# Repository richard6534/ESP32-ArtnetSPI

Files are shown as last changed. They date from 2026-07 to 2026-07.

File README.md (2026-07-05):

# ESP32-ArtnetSPI
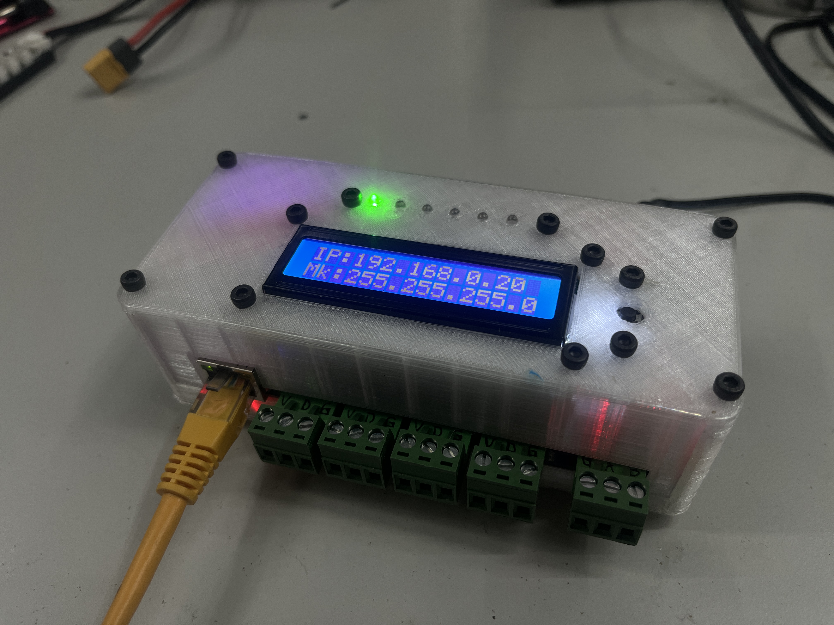
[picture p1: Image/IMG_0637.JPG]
Image Description


這款 Artnet SPI ESP32 LED 控制器是一款高效能的開源解決方案，可透過乙太網路或 Wi-Fi 控制可尋址 LED。此專案可讓您使用 Artnet 協議，透過配備 W5500 乙太網路模組及 ESP32 微控制器來控制多個 LED 燈條。程式碼包含一個簡單的 Web 伺服器，用於配置和控制 LED 燈條。為了獲得最佳效能。

## Features

- 4 個輸出端口，共 16 個燈路：每個輸出端口最多可連接 4 條 LED 燈帶，每個輸出端口有 4 個燈路，可實現大規模 LED 安裝。
- 1 個DMX輸出端口，可連接DMX相關設備。
- 支援 3 色（RGB）、4 色（RGBW）和 5 色（RGBAW）LED。
- 支援 3 線 LED (WS28xx) 和 4 線 SPI 時脈 LED (APA102)。
- 支援乙太網路和 Wi-Fi：支援有線和無線 Art-Net 控制，實現靈活的連線。
- 靜態 IP 位址選項適用於永久安裝。
- 用於在 artnet、靜態 IP、RGB 測試和靜態顏色之間切換模式的實體按鈕。
- 透過空中下載 (OTA) 更新，可以輕鬆地將您的節點更新到不同版本。
- 透過網頁介面配置 LED 數量、輸出埠、起始和節點名稱。
- 高幀率：超過 40 FPS，取決於所使用的軟體。
- 效能可靠：可靠性高達 99% 以上，丟幀率低於 1%。
- 支援 128x32 OLED 顯示器：提供即時狀態更新和設定回饋。
- 狀態 RGB LED：指示設備狀態，方便調試和監控。
- RGB 測試循環：利用內建循環模式快速測試 LED 輸出。
- 完全開源：包含 PCB 設計和 BOM，使用戶能夠建立自己經濟高效的控制器。

## Design Drawing

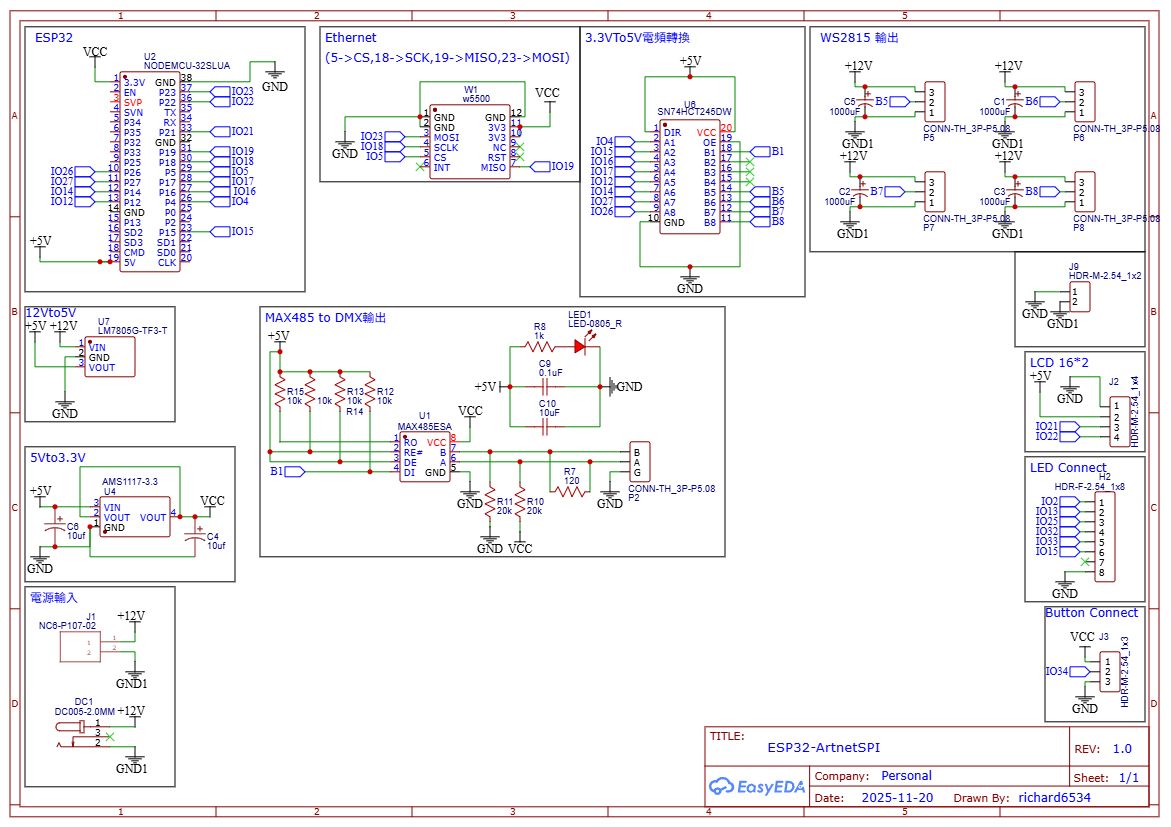
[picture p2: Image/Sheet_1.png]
Image Description

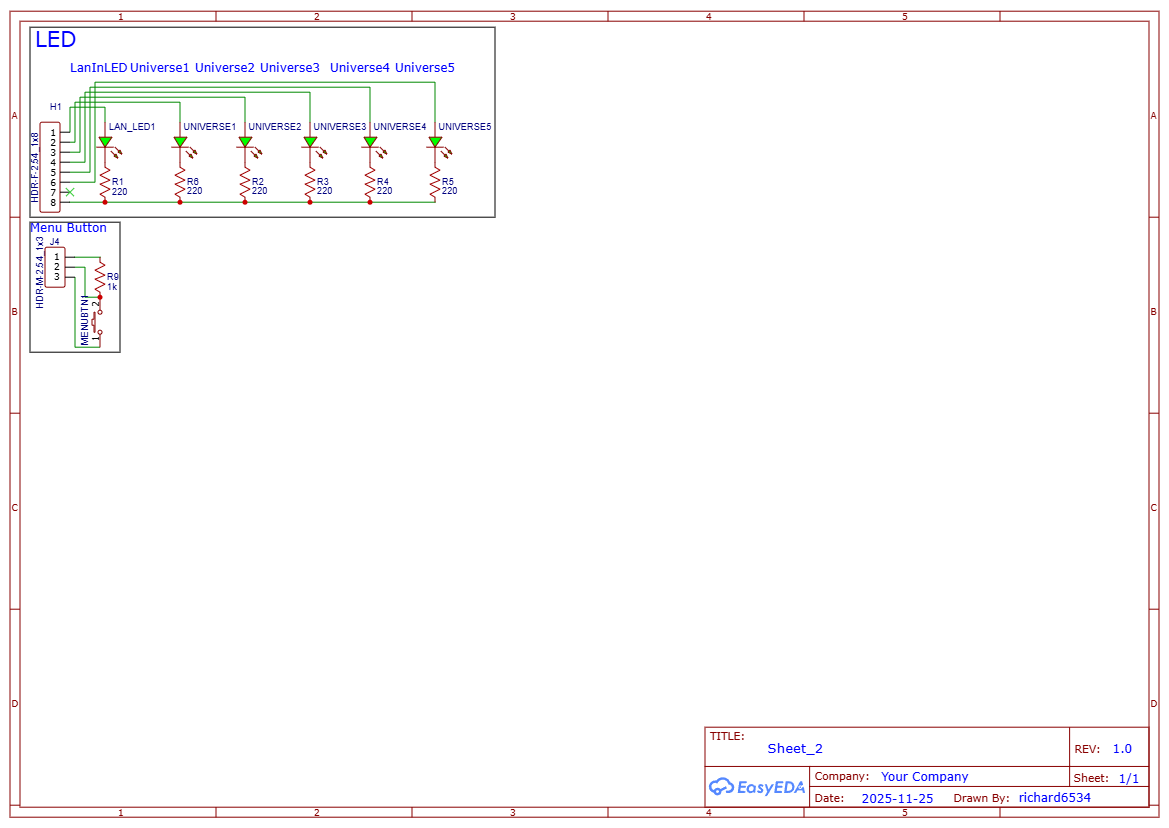
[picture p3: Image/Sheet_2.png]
Image Description


## PCB Design

- 這是正在進行中的PCB設計，採用12V轉5V降壓轉換器，並使用螺絲端子方便連接。

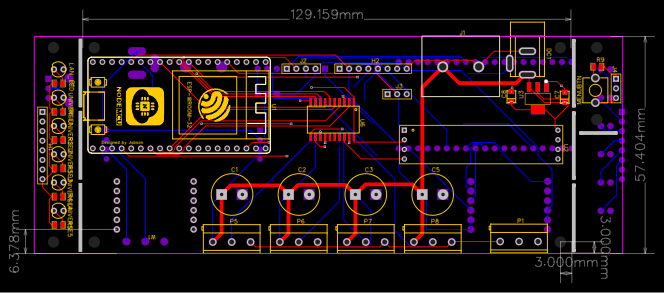
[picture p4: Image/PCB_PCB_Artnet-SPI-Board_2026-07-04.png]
Image Description


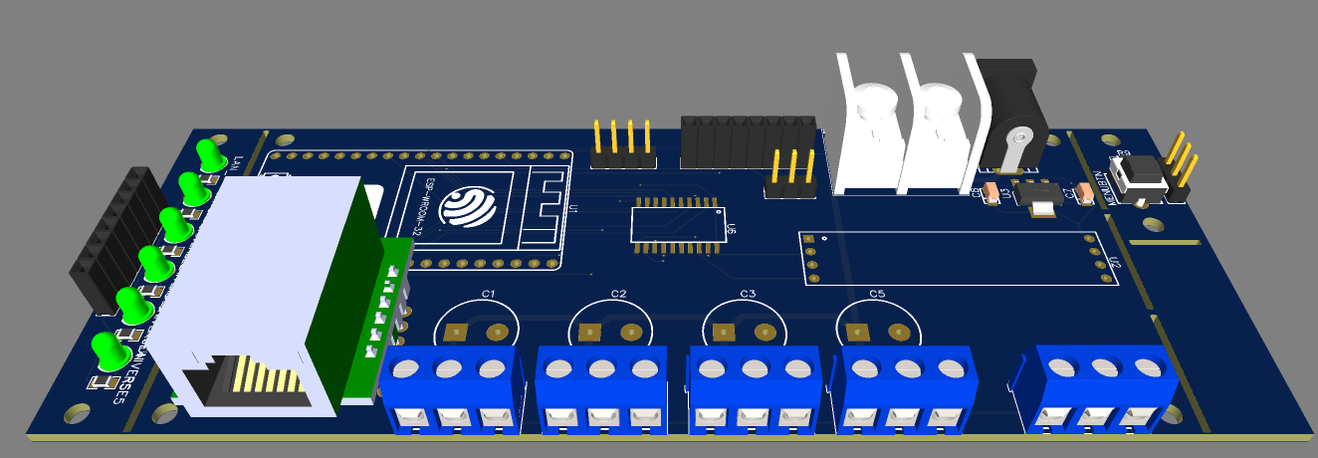
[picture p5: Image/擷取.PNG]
Image Description


## BOM

BOM_Artnet-SPI-Board.csv

## Hardware Requirements

- ESP32-S2-NodeMCU 
- W5500 Ethernet module
- WS2812 RGB 狀態指示燈（可選，用於狀態指示）)
- 12v/5v Power Supply

**Important!** 僅支援部分 ESP32 型號！使用 W5500 時，請查看 WebServer_ESP32_W5500 以了解支援的開發板。

## Software Requirements

- Arduino IDE with ESP32 support
- Espressif ESP32 board manager library
  - Use https://espressif.github.io/arduino-esp32/package_esp32_index.json
  - Version 2.0.17 or lower, otherwise compilation errors arise

## Supported LED ICs

All LEDs based on the wsXXXX and clocked LED series are supported. These can be 3, 4, or 5 channel LEDs. These include, but are not limited to:
  - WS2805, WS2811, WS2812, WS2813, WS2814, WS2815 (Tested)
  - APA102, SK6812 SPI-based LEDs (Tested)
  - SK6812, SK6812W, SK6812-mini (Not tested)
  - GS8208, TM1814, TM1829, UCS8904, UCS8903, FW1906 (Not tested)

# Configuration

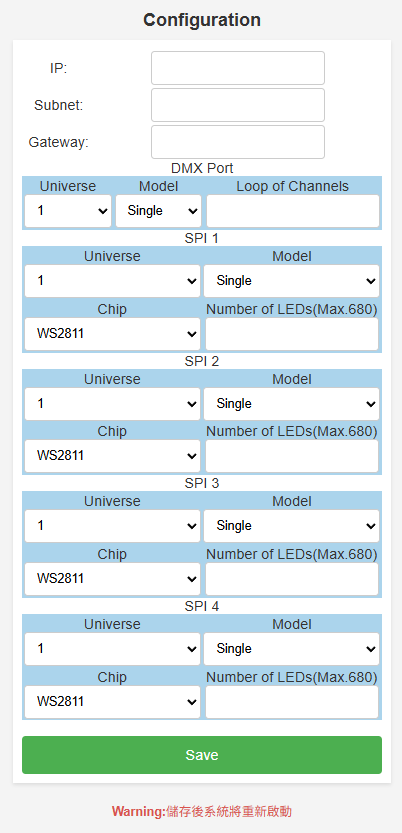
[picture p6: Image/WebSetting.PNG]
Image Description


## Access the Web Interface:
- 上傳程式碼後，使用 W5500 乙太網路模組將 ESP32 連接到網路。
- 找到指派給 ESP32 的 IP 位址，並在網頁瀏覽器中開啟它。
  - 若要輕鬆尋找 IP 位址，可以按上面的按鈕，即會顯示IP及目前設定。

# Test

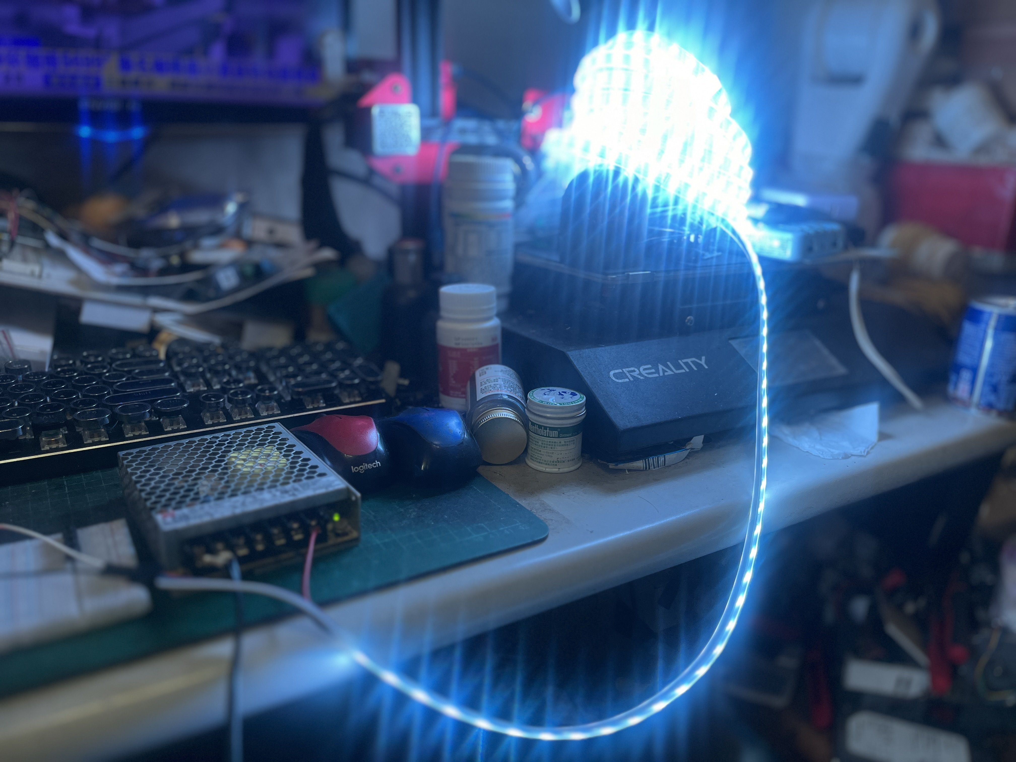
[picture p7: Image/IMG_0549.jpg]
Image Description


## Open-Source Contributions
This project is fully open-source! Feel free to contribute improvements, share your builds, and collaborate with the community.

##License
This project is released under the MIT License. You are free to use, modify, and distribute it with proper attribution.

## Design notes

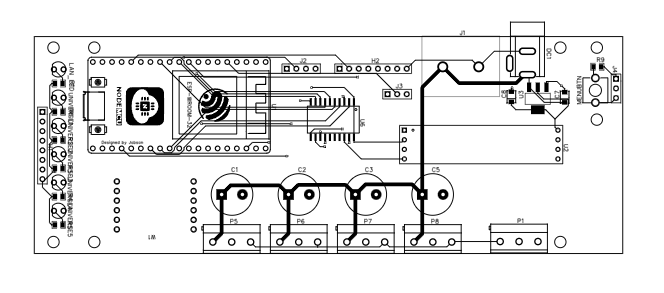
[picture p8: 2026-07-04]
Image/PCB_PCB_Artnet-SPI-Board_2026-04-16.png

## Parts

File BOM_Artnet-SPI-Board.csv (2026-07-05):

ID | Name | Designator | Footprint | Quantity | Manufacturer Part | Manufacturer | Supplier | Supplier Part
1 | 1000uF | C1,C2,C3,C5 | CAPACITOR1000UF16V | 4 | electrolytic capacitor10UF50V | ValuePro | LCSC | C32856
2 | DC005-2.0MM | DC1 | DC-IN-TH_DC005 | 1 | DC005-2.0MM | SOFNG | LCSC | C111567
3 | HDR-F-2.54_1x8 | H1,H2 | HDR-F-2.54_1X8 | 2 |  |  | LCSC | C225505
4 | NC6-P107-02 | J1 | NC6P10702 | 1 | NC6-P107-02 | TE Connectivity | Mouser | 571-14376644
5 | HDR-M-2.54_1x4 | J2 | HDR-M-2.54_1X4 | 1 |  |  | LCSC | C124378
6 | HDR-M-2.54_1x3 | J3,J4 | HDR-M-2.54_1X3 | 2 |  |  | LCSC | C180248
7 | LED-0805_G | LAN_LED1,UNIVERSE1,UNIVERSE2,UNIVERSE3,UNIVERSE4,UNIVERSE5 | LED0805_GREEN | 6 | NCD0805G1 | 国星光电 |  | C84260
8 | K2-3.6×6.1_SMD | MENUBTN1 | KEY-TH_L6.6-W6.3-P6.50-L | 1 | K2-1107ST-A4SW-06 |  | LCSC | C118141
9 | CONN-TH_3P-P5.08 | P1,P5,P6,P7,P8 | CONN-TH_3P-P5.08 | 5 |  |  | LCSC
10 | 220 | R1,R2,R3,R4,R5,R6 | R0805 | 6
11 | 1k | R9 | R0805 | 1
12 | NODEMCU-32SLUA | U1 | COMM-TH_NODEMCU-32SLUA | 1 | NodeMCU-32SLua | Ai-Thinker(安信可) | LCSC | C111436
13 | MAX485 | U2 | MAX485MODULE_FP | 1 | MAX485EESA+ | ADI(亚德诺)/MAXIM(美信) | LCSC | C7456067
14 | LM7805G-TF3-T | U3 | TO-220F-3_L10.2-W4.7-P2.54-L | 1 | LM7805G-TF3-T | UTC(友顺) | LCSC | C213490
15 | SN74HCT245DW | U6 | SOIC-20 | 1
16 | w5500 | W1 | W5500 | 1

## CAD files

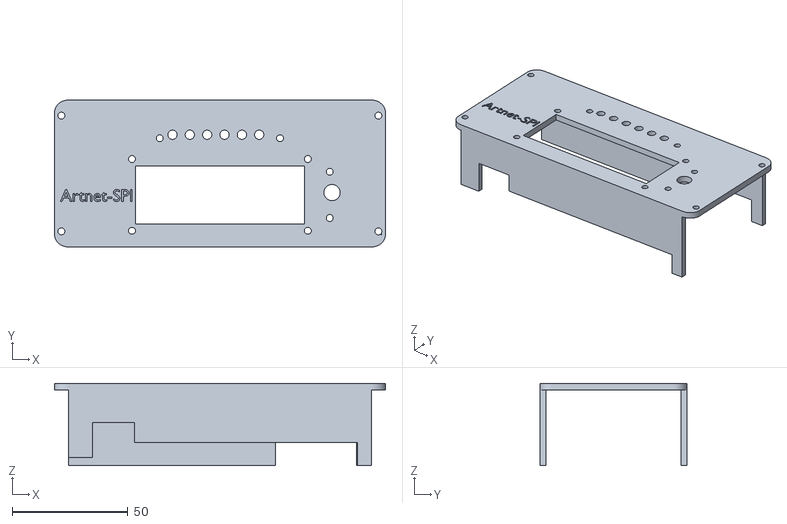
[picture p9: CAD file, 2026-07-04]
3DPrintFile/TopV2.stl
143.1 x 63.5 x 35.6

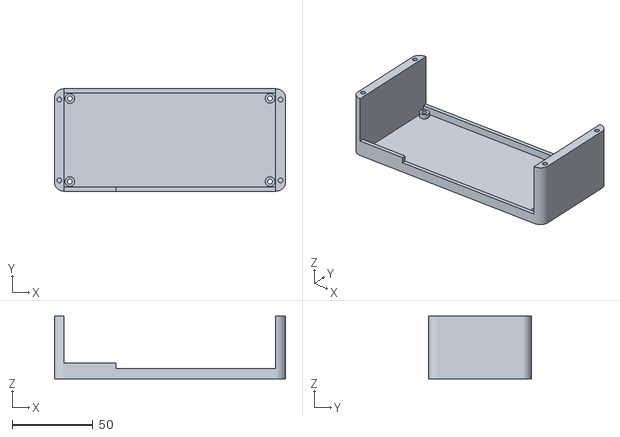
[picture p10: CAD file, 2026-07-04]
3DPrintFile/ButtomV2.stl
143.0 x 63.5 x 38.9

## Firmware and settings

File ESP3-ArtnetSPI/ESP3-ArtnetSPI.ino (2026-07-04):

#include <SPI.h>
#include <EEPROM.h>
#include <Ethernet.h>
#include <ArtnetEther.h>
#include <FastLED.h>
#include "HTML_UrlEncode.h"
#include "ESPDMX.h"
#include <Arduino.h>
#include <LiquidCrystal_I2C.h>
//---------------------------------------------------------------
// Set the static IP address to use if the DHCP fails to assign
// W5500 (5->CS,18->SCK,19->MISO,23->MOSI)
// replace the MAC address below by the MAC address printed on a sticker on the Arduino Shield 2
byte mac[] = { 0xDE, 0xAD, 0xBE, 0xEF, 0xFE, 0xEF };
EthernetClient client;
//---------------------------------------------------------------
ArtnetEtherReceiver artnet;
uint16_t universe1 = 0; 
uint16_t universe2 = 1;  
uint16_t universe3 = 2;  
uint16_t universe4 = 3;
uint16_t universe5 = 4;  
//---------------------------------------------------------------
// FastLED settings
const int numLeds = 512; // CHANGE FOR YOUR SETUP
const int numberOfChannels = numLeds * 3; // Total number of channels you want to receive (1 led = 3 channels)
//12, 14, 27, 26
const byte dataPin1 = 12;
const byte dataPin2 = 14;
const byte dataPin3 = 27;
const byte dataPin4 = 26;
CRGB leds1[numLeds];
CRGB leds2[numLeds];
CRGB leds3[numLeds];
CRGB leds4[numLeds];
//---------------------------------------------------------------
//LED Lan Universe1 Universe2 Universe3 Universe4->2,13,25,32,33,15
const byte Lan_LedPin = 2;
const byte UNI1_LedPin = 13;
const byte UNI2_LedPin = 25;
const byte UNI3_LedPin = 32;
const byte UNI4_LedPin = 33;
const byte UNI5_LedPin = 15;
//WebServer----------------------------------------------------------------
EthernetServer server(80);
String currentLine = "";                // make a String to hold incoming data from the client
String CMDString = "";
bool isCMD = false;
//DMX---------------------------------------------------------------
const byte DMXPin1 = 4;
DMXESPSerial dmx1;
//儲存程序----------------------------------------------------------
//EEPROM MAX 512
#define EEPROM_Status_SIZE 1
#define EEPROM_Status_Addr 0
byte IOT_Status = 0;
//StaticIP-----------------------------------------------------------
#define EEPROM_StaticIP_SIZE 20
#define EEPROM_StaticIP_Addr 1
//Subnet-------------------------------------------------------------------
#define EEPROM_Subnet_SIZE 20
#define EEPROM_Subnet_Addr 21
//Gateway-------------------------------------------------------------------
#define EEPROM_Gateway_SIZE 20
#define EEPROM_Gateway_Addr 41
//DMXPort_Universe-------------------------------------------------------------------
#define EEPROM_DMXPort_Universe_SIZE 1
#define EEPROM_DMXPort_Universe_Addr 61
//DMXPort_Model-------------------------------------------------------------------
#define EEPROM_DMXPort_Model_SIZE 1
#define EEPROM_DMXPort_Model_Addr 62
//DMXPort_Loop-------------------------------------------------------------------
#define EEPROM_DMXPort_Leds_SIZE 4
#define EEPROM_DMXPort_Leds_Addr 63
//SPI1_Universe-------------------------------------------------------------------
#define EEPROM_SPI1_Universe_SIZE 1
#define EEPROM_SPI1_Universe_Addr 67
//SPI1_Model-------------------------------------------------------------------
#define EEPROM_SPI1_Model_SIZE 1
#define EEPROM_SPI1_Model_Addr 68
//SPI1_Chip-------------------------------------------------------------------
#define EEPROM_SPI1_Chip_SIZE 1
#define EEPROM_SPI1_Chip_Addr 69
//SPI1_Leds-------------------------------------------------------------------
#define EEPROM_SPI1_Leds_SIZE 4
#define EEPROM_SPI1_Leds_Addr 70
//SPI2_Universe-------------------------------------------------------------------
#define EEPROM_SPI2_Universe_SIZE 1
#define EEPROM_SPI2_Universe_Addr 74
//SPI2_Model-------------------------------------------------------------------
#define EEPROM_SPI2_Model_SIZE 1
#define EEPROM_SPI2_Model_Addr 75
//SPI2_Chip-------------------------------------------------------------------
#define EEPROM_SPI2_Chip_SIZE 1
#define EEPROM_SPI2_Chip_Addr 76
//SPI2_Leds-------------------------------------------------------------------
#define EEPROM_SPI2_Leds_SIZE 4
#define EEPROM_SPI2_Leds_Addr 77
//SPI3_Universe-------------------------------------------------------------------
#define EEPROM_SPI3_Universe_SIZE 1
#define EEPROM_SPI3_Universe_Addr 81
//SPI3_Model-------------------------------------------------------------------
#define EEPROM_SPI3_Model_SIZE 1
#define EEPROM_SPI3_Model_Addr 82
//SPI3_Chip-------------------------------------------------------------------
#define EEPROM_SPI3_Chip_SIZE 1
#define EEPROM_SPI3_Chip_Addr 83
//SPI3_Leds-------------------------------------------------------------------
#define EEPROM_SPI3_Leds_SIZE 4
#define EEPROM_SPI3_Leds_Addr 84
//SPI4_Universe-------------------------------------------------------------------
#define EEPROM_SPI4_Universe_SIZE 1
#define EEPROM_SPI4_Universe_Addr 89
//SPI4_Model-------------------------------------------------------------------
#define EEPROM_SPI4_Model_SIZE 1
#define EEPROM_SPI4_Model_Addr 90
//SPI4_Chip-------------------------------------------------------------------
#define EEPROM_SPI4_Chip_SIZE 1
#define EEPROM_SPI4_Chip_Addr 91
//SPI4_Leds-------------------------------------------------------------------
#define EEPROM_SPI4_Leds_SIZE 4
#define EEPROM_SPI4_Leds_Addr 92
//-------------------------------------------------------------------
int EEPROM_Total = EEPROM_Status_SIZE + EEPROM_StaticIP_SIZE + EEPROM_Subnet_SIZE + EEPROM_Gateway_SIZE + 
                  EEPROM_DMXPort_Universe_SIZE + EEPROM_DMXPort_Model_SIZE + EEPROM_DMXPort_Leds_Addr + 
                  EEPROM_SPI1_Universe_SIZE + EEPROM_SPI1_Model_SIZE + EEPROM_SPI1_Chip_SIZE + EEPROM_SPI1_Leds_Addr + 
                  EEPROM_SPI2_Universe_SIZE + EEPROM_SPI2_Model_SIZE + EEPROM_SPI2_Chip_SIZE + EEPROM_SPI2_Leds_Addr + 
                  EEPROM_SPI3_Universe_SIZE + EEPROM_SPI3_Model_SIZE + EEPROM_SPI3_Chip_SIZE + EEPROM_SPI3_Leds_Addr +
                  EEPROM_SPI4_Universe_SIZE + EEPROM_SPI4_Model_SIZE + EEPROM_SPI4_Chip_SIZE + EEPROM_SPI4_Leds_Addr;
//-------------------------------------------------------------------
#pragma pack(push)
#pragma  pack(1)
//-----------------------------------------------------------------------
struct IOT_Config
{
  char  StaticIP[20];
  char  Subnet[20];
  char  Gateway[20];
  //0~5:Universe
  byte      DMXPort_Universe;
  //0:Single,1:Total
  byte      DMXPort_Model;
  int       DMXPort_Leds;
  //0~5:Universe
  byte      SPI1_Universe;
  //0:Single,1:Total
  byte      SPI1_Model;
  //0:WS2811,1:WS2812,2:WS2815
  byte      SPI1_Chip;
  int       SPI1_Leds;  
  //0~5:Universe
  byte      SPI2_Universe;
  //0:Single,1:Total
  byte      SPI2_Model;
  //0:WS2811,1:WS2812,2:WS2815
  byte      SPI2_Chip;
  int       SPI2_Leds;  
  //0~5:Universe
  byte      SPI3_Universe;
  //0:Single,1:Total
  byte      SPI3_Model;
  //0:WS2811,1:WS2812,2:WS2815
  byte      SPI3_Chip;
  int       SPI3_Leds;  
  //0~5:Universe
  byte      SPI4_Universe;
  //0:Single,1:Total
  byte      SPI4_Model;
  //0:WS2811,1:WS2812,2:WS2815
  byte      SPI4_Chip;
  int       SPI4_Leds;  
};
int IOT_Config_LEN = sizeof(IOT_Config);
//-----------------------------------------------------------------------
IOT_Config _Config;
//-----------------------------------------------------------------------
#pragma pack(pop)
//---------------------------------------------------------------
//LCD 
const byte Lcd_BtnPin = 34;
const byte Lcd_SDA = 21;
const byte Lcd_SCL = 22;
const byte lcdColumns = 16;
const byte lcdRows = 2;
byte lcdPage=0;
int BtnChange = LOW;
LiquidCrystal_I2C lcd(0x27, lcdColumns, lcdRows);
//---------------------------------------------------------------
void setup() {
  Serial.begin(115200);
  delay(1000);
  LoadConfig();
  Ethernet_Initial();
  Arnet_Initial();
  FastLED_Initial();
  WebServer_Initial();
  LED_Initial();
  LCD_Initial();
  DMX_Initial();
}
//---------------------------------------------------------------
void loop() {
  Ethernet_Loop();
  Artnet_Loop();
  WebServer_Loop();    
  LCD_Loop();
  DMX_Loop();
  digitalWrite(UNI1_LedPin, LOW);
  digitalWrite(UNI2_LedPin, LOW);
  digitalWrite(UNI3_LedPin, LOW);
  digitalWrite(UNI4_LedPin, LOW);
  digitalWrite(UNI5_LedPin, LOW);
}
//---------------------------------------------------------------
void LoadConfig(){

    EEPROM.begin(EEPROM_Total);
    //判定是否設定過
    IOT_Status = EEPROM.read(EEPROM_Status_Addr);
    Serial.print("IOT_Status:");
    Serial.println(IOT_Status);    
    if(IOT_Status == 1)
    {//己設定過
      //staticIP
      for (int i = 0; i < EEPROM_StaticIP_SIZE; i++) {
        EEPROM.get(EEPROM_StaticIP_Addr + i, _Config.StaticIP[i]);
      }   
      for (int i = 0; i < EEPROM_Subnet_SIZE; i++) {
        EEPROM.get(EEPROM_Subnet_Addr + i, _Config.Subnet[i]);
      }
      for (int i = 0; i < EEPROM_Gateway_SIZE; i++) {
        EEPROM.get(EEPROM_Gateway_Addr + i, _Config.Gateway[i]);
      }     
      _Config.DMXPort_Universe = EEPROM.read(EEPROM_DMXPort_Universe_Addr);
      _Config.DMXPort_Model = EEPROM.read(EEPROM_DMXPort_Model_Addr);
      _Config.DMXPort_Leds = ReadIntFromEEPROM(EEPROM_DMXPort_Leds_Addr);

      _Config.SPI1_Universe = EEPROM.read(EEPROM_SPI1_Universe_Addr);
      _Config.SPI1_Model = EEPROM.read(EEPROM_SPI1_Model_Addr);
      _Config.SPI1_Chip = EEPROM.read(EEPROM_SPI1_Chip_Addr);
      _Config.SPI1_Leds = ReadIntFromEEPROM(EEPROM_SPI1_Leds_Addr);
            
      _Config.SPI2_Universe = EEPROM.read(EEPROM_SPI2_Universe_Addr);
      _Config.SPI2_Model = EEPROM.read(EEPROM_SPI2_Model_Addr);
      _Config.SPI2_Chip = EEPROM.read(EEPROM_SPI2_Chip_Addr);
      _Config.SPI2_Leds = ReadIntFromEEPROM(EEPROM_SPI2_Leds_Addr);
            
      _Config.SPI3_Universe = EEPROM.read(EEPROM_SPI3_Universe_Addr);
      _Config.SPI3_Model = EEPROM.read(EEPROM_SPI3_Model_Addr);
      _Config.SPI3_Chip = EEPROM.read(EEPROM_SPI3_Chip_Addr);
      _Config.SPI3_Leds = ReadIntFromEEPROM(EEPROM_SPI3_Leds_Addr);
          
      _Config.SPI4_Universe = EEPROM.read(EEPROM_SPI4_Universe_Addr);
      _Config.SPI4_Model = EEPROM.read(EEPROM_SPI4_Model_Addr);
      _Config.SPI4_Chip = EEPROM.read(EEPROM_SPI4_Chip_Addr);
      _Config.SPI4_Leds = ReadIntFromEEPROM(EEPROM_SPI4_Leds_Addr);                  
    }
    else
    {//未設定過
      strcpy(_Config.StaticIP,"192.168.0.10");//預設IP
      strcpy(_Config.Subnet,"255.255.255.0");//預設
      strcpy(_Config.Gateway,"192.168.0.1");//預設
      _Config.DMXPort_Universe=0;
      _Config.DMXPort_Model=0;
      _Config.DMXPort_Leds=0;      
      _Config.SPI1_Universe=0;
      _Config.SPI1_Model=0;
      _Config.SPI1_Chip=0;
      _Config.SPI1_Leds=0;
      _Config.SPI2_Universe=0;
      _Config.SPI2_Model=0;
      _Config.SPI2_Chip=0;
      _Config.SPI2_Leds=0;
      _Config.SPI3_Universe=0;
      _Config.SPI3_Model=0;
      _Config.SPI3_Chip=0;
      _Config.SPI3_Leds=0;
      _Config.SPI4_Universe=0;
      _Config.SPI4_Model=0;
      _Config.SPI4_Chip=0;
      _Config.SPI4_Leds=0;                  
    }
      //偵錯
      Serial.print("StaticIP:");
      Serial.println(_Config.StaticIP);
      Serial.print("Subnet:");
      Serial.println(_Config.Subnet);
      Serial.print("Gateway:");
      Serial.println(_Config.Gateway);

      Serial.print("DMXPort_Universe:");
      Serial.println(_Config.DMXPort_Universe);
      Serial.print("DMXPort_Model:");
      Serial.println(_Config.DMXPort_Model);
      Serial.print("DMXPort_Leds:");
      Serial.println(_Config.DMXPort_Leds);
      
      Serial.print("SPI1_Universe:");
      Serial.println(_Config.SPI1_Universe);
      Serial.print("SPI1_Model:");
      Serial.println(_Config.SPI1_Model);
      Serial.print("SPI1_Chip:");
      Serial.println(_Config.SPI1_Chip);
      Serial.print("SPI1_Leds:");
      Serial.println(_Config.SPI1_Leds);

      Serial.print("SPI2_Universe:");
      Serial.println(_Config.SPI2_Universe);
      Serial.print("SPI2_Model:");
      Serial.println(_Config.SPI2_Model);
      Serial.print("SPI2_Chip:");
      Serial.println(_Config.SPI2_Chip);
      Serial.print("SPI2_Leds:");
      Serial.println(_Config.SPI2_Leds);      

      Serial.print("SPI3_Universe:");
      Serial.println(_Config.SPI3_Universe);
      Serial.print("SPI3_Model:");
      Serial.println(_Config.SPI3_Model);
      Serial.print("SPI3_Chip:");
      Serial.println(_Config.SPI3_Chip);
      Serial.print("SPI3_Leds:");
      Serial.println(_Config.SPI3_Leds); 

      Serial.print("SPI4_Universe:");
      Serial.println(_Config.SPI4_Universe);
      Serial.print("SPI4_Model:");
      Serial.println(_Config.SPI4_Model);
      Serial.print("SPI4_Chip:");
      Serial.println(_Config.SPI4_Chip);
      Serial.print("SPI4_Leds:");
      Serial.println(_Config.SPI4_Leds); 
}
//---------------------------------------------------------------
void SaveConfig()
{
  //狀態
  EEPROM.write(EEPROM_Status_Addr, 1);
    //儲存StaticIP
  for (int i = 0; i < EEPROM_StaticIP_SIZE; i++) {
    EEPROM.put(EEPROM_StaticIP_Addr + i, _Config.StaticIP[i]);
  }
  for (int i = 0; i < EEPROM_Subnet_SIZE; i++) {
    EEPROM.put(EEPROM_Subnet_Addr + i, _Config.Subnet[i]);
  }
  for (int i = 0; i < EEPROM_Gateway_SIZE; i++) {
    EEPROM.put(EEPROM_Gateway_Addr + i, _Config.Gateway[i]);
  }  
  EEPROM.write(EEPROM_DMXPort_Universe_Addr, _Config.DMXPort_Universe);
  EEPROM.write(EEPROM_DMXPort_Model_Addr, _Config.DMXPort_Model);
  WriteIntIntoEEPROM(EEPROM_DMXPort_Leds_Addr, _Config.DMXPort_Leds);
    
  EEPROM.write(EEPROM_SPI1_Universe_Addr, _Config.SPI1_Universe);
  EEPROM.write(EEPROM_SPI1_Model_Addr, _Config.SPI1_Model);
  EEPROM.write(EEPROM_SPI1_Chip_Addr, _Config.SPI1_Chip);
  WriteIntIntoEEPROM(EEPROM_SPI1_Leds_Addr, _Config.SPI1_Leds);

  EEPROM.write(EEPROM_SPI2_Universe_Addr, _Config.SPI2_Universe);
  EEPROM.write(EEPROM_SPI2_Model_Addr, _Config.SPI2_Model);
  EEPROM.write(EEPROM_SPI2_Chip_Addr, _Config.SPI2_Chip);
  WriteIntIntoEEPROM(EEPROM_SPI2_Leds_Addr, _Config.SPI2_Leds);

  EEPROM.write(EEPROM_SPI3_Universe_Addr, _Config.SPI3_Universe);
  EEPROM.write(EEPROM_SPI3_Model_Addr, _Config.SPI3_Model);
  EEPROM.write(EEPROM_SPI3_Chip_Addr, _Config.SPI3_Chip);
  WriteIntIntoEEPROM(EEPROM_SPI3_Leds_Addr, _Config.SPI3_Leds);

  EEPROM.write(EEPROM_SPI4_Universe_Addr, _Config.SPI4_Universe);
  EEPROM.write(EEPROM_SPI4_Model_Addr, _Config.SPI4_Model);
  EEPROM.write(EEPROM_SPI4_Chip_Addr, _Config.SPI4_Chip);
  WriteIntIntoEEPROM(EEPROM_SPI4_Leds_Addr, _Config.SPI4_Leds);      

  EEPROM.commit();
}
//-------------------------------------------------------------------
void WriteIntIntoEEPROM(int address, int number)
{
  EEPROM.write(address, number >> 8);
  EEPROM.write(address + 1, number & 0xFF);
}
//-------------------------------------------------------------------
int ReadIntFromEEPROM(int address)
{
  byte byte1 = EEPROM.read(address);
  byte byte2 = EEPROM.read(address + 1);
  return (byte1 << 8) + byte2;
}
//---------------------------------------------------------------
void LCD_Initial()
{
  pinMode(Lcd_BtnPin, INPUT);
  // initialize LCD
  lcd.init();
  // turn on LCD backlight                      
  //lcd.backlight();  
  lcd.noBacklight();
}
//-------------------------------------------------------------------
void LCD_Loop()
{
  // read the state of the pushbutton value:
  int buttonState = digitalRead(Lcd_BtnPin);
  // check if the pushbutton is pressed. If it is, the buttonState is HIGH:
  if (buttonState == HIGH) {
    if(BtnChange==false){
      if(lcdPage==0){
          lcd.noBacklight();
          lcdPage++;          
      }
      else if(lcdPage==1)
      {
        lcd.backlight();
        lcd.clear();
        String Content="IP:" + String(_Config.StaticIP);
        LCD_SetText(0,0,Content);
        Content = "Mk:" + String(_Config.Subnet);
        LCD_SetText(0,1,Content);
        lcdPage++;
      }
      else if(lcdPage==2)
      {
        lcd.clear();
        String Content="Gw:" + String(_Config.Gateway);
        LCD_SetText(0,0,Content);
        lcdPage++;        
      }
      else if(lcdPage==3)
      {
        lcd.clear();
        String Content="DMX Uni:" + String(_Config.DMXPort_Universe);
        LCD_SetText(0,0,Content);
        Content="DMX Model:" + String(_Config.DMXPort_Model);
        LCD_SetText(0,1,Content);        
        lcdPage++;   
      }
      else if(lcdPage==4)
      {
        lcd.clear();
        String Content="DMX Loop:" + String(_Config.DMXPort_Leds);
        LCD_SetText(0,0,Content);
        lcdPage++; 
      }
      else if(lcdPage==5)
      {
        lcd.clear();
        String Content="SPI1 Uni:" + String(_Config.SPI1_Universe);
        LCD_SetText(0,0,Content);
        Content="SPI1 Model:" + String(_Config.SPI1_Model);
        LCD_SetText(0,1,Content);        
        lcdPage++; 
      }
      else if(lcdPage==6)
      {
        lcd.clear();
        String Content="SPI1 Chip:" + String(_Config.SPI1_Chip);
        LCD_SetText(0,0,Content);
        Content="SPI1 Leds:" + String(_Config.SPI1_Leds);
        LCD_SetText(0,1,Content);        
        lcdPage++;   
      }
      else if(lcdPage==7)
      {
        lcd.clear();
        String Content="SPI2 Uni:" + String(_Config.SPI2_Universe);
        LCD_SetText(0,0,Content);
        Content="SPI2 Model:" + String(_Config.SPI2_Model);
        LCD_SetText(0,1,Content);        
        lcdPage++; 
      }
      else if(lcdPage==8)
      {
        lcd.clear();
        String Content="SPI2 Chip:" + String(_Config.SPI2_Chip);
        LCD_SetText(0,0,Content);
        Content="SPI2 Leds:" + String(_Config.SPI2_Leds);
        LCD_SetText(0,1,Content);        
        lcdPage++;      
      }
      else if(lcdPage==9)
      {
        lcd.clear();
        String Content="SPI3 Uni:" + String(_Config.SPI3_Universe);
        LCD_SetText(0,0,Content);
        Content="SPI3 Model:" + String(_Config.SPI3_Model);
        LCD_SetText(0,1,Content);        
        lcdPage++; 
      }
      else if(lcdPage==10)
      {
        lcd.clear();
        String Content="SPI3 Chip:" + String(_Config.SPI3_Chip);
        LCD_SetText(0,0,Content);
        Content="SPI3 Leds:" + String(_Config.SPI3_Leds);
        LCD_SetText(0,1,Content);        
        lcdPage++;        
      }
      else if(lcdPage==11)
      {
        lcd.clear();
        String Content="SPI4 Uni:" + String(_Config.SPI4_Universe);
        LCD_SetText(0,0,Content);
        Content="SPI4 Model:" + String(_Config.SPI4_Model);
        LCD_SetText(0,1,Content);        
        lcdPage++; 
      }
      else if(lcdPage==12)
      {
        lcd.clear();
        String Content="SPI4 Chip:" + String(_Config.SPI4_Chip);
        LCD_SetText(0,0,Content);
        Content="SPI4 Leds:" + String(_Config.SPI4_Leds);
        LCD_SetText(0,1,Content);        
        lcdPage++;  
      }
      else if(lcdPage==13)
      {        
          lcd.noBacklight();
          lcdPage=0;                                         
      }      
      BtnChange = buttonState;
    }
  } 
  else BtnChange = LOW;
}
//---------------------------------------------------------------
void LCD_SetText(int x,int y,String Msg){
  lcd.setCursor(x, y);  
  lcd.print(Msg);
}
//---------------------------------------------------------------
void LED_Initial()
{
  pinMode(Lan_LedPin, OUTPUT);
  pinMode(UNI1_LedPin, OUTPUT);
  pinMode(UNI2_LedPin, OUTPUT);
  pinMode(UNI3_LedPin, OUTPUT);
  pinMode(UNI4_LedPin, OUTPUT);
  pinMode(UNI5_LedPin, OUTPUT);
  digitalWrite(Lan_LedPin, LOW);
  digitalWrite(UNI1_LedPin, LOW);
  digitalWrite(UNI2_LedPin, LOW);
  digitalWrite(UNI3_LedPin, LOW);    
  digitalWrite(UNI4_LedPin, LOW);  
  digitalWrite(UNI5_LedPin, LOW);  
}
//---------------------------------------------------------------
void FastLED_Initial()
{
  FastLED.addLeds<WS2815, dataPin1, RGB>(leds1, numLeds);
  FastLED.addLeds<WS2815, dataPin2, RGB>(leds2, numLeds);
  FastLED.addLeds<WS2815, dataPin3, RGB>(leds3, numLeds);
  FastLED.addLeds<WS2815, dataPin4, RGB>(leds4, numLeds);
  FastLED.setBrightness(255);
}
//---------------------------------------------------------------
void Arnet_Initial()
{
  artnet.begin();
  artnet.subscribeArtDmxUniverse(universe1, callback1);  
  artnet.subscribeArtDmxUniverse(universe2, callback2);
  artnet.subscribeArtDmxUniverse(universe3, callback3);
  artnet.subscribeArtDmxUniverse(universe4, callback4);
  artnet.subscribeArtDmxUniverse(universe5, callback5);
  Serial.println("ESP32 - Arnet Initialed");         
}
//---------------------------------------------------------------
void Artnet_Loop()
{
  artnet.parse();  
}
//---------------------------------------------------------------
void callback1(const uint8_t *data, uint16_t size, const ArtDmxMetadata &metadata, const ArtNetRemoteInfo &remote) {
  Serial.print(data[0]);
  Serial.print(",");
  Serial.print(data[1]);
  Serial.print(",");
  Serial.print(data[2]);
  Serial.print(",");  
  Serial.print(data[3]);
  Serial.print(",");
  Serial.print(data[4]);
  Serial.print(",");
  Serial.print(data[5]);  
  Serial.print(",");
  Serial.print(size);    
  Serial.println();
  digitalWrite(UNI1_LedPin, HIGH);
  DMXPort_CallBack(0,data,size);
  SPI1_CallBack(0,data,size);
  SPI2_CallBack(0,data,size);
  SPI3_CallBack(0,data,size);
  SPI4_CallBack(0,data,size);
}
//---------------------------------------------------------------
void callback2(const uint8_t *data, uint16_t size, const ArtDmxMetadata &metadata, const ArtNetRemoteInfo &remote) {
  digitalWrite(UNI2_LedPin, HIGH);  
  DMXPort_CallBack(1,data,size);
  SPI1_CallBack(1,data,size);
  SPI2_CallBack(1,data,size);
  SPI3_CallBack(1,data,size);
  SPI4_CallBack(1,data,size);
}
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

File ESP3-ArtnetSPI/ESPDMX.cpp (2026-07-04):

// - - - - -
// ESPDMX - A Arduino library for sending and receiving DMX using the builtin serial hardware port.
// ESPDMX.cpp: Library implementation file
//
// Copyright (C) 2015  Rick <ricardogg95@gmail.com>
// This work is licensed under a GNU style license.
//
// Last change: Marcel Seerig <https://github.com/mseerig>
//
// Documentation and samples are available at https://github.com/Rickgg/ESP-Dmx
// - - - - -

/* ----- LIBRARIES ----- */
#include <Arduino.h>

#include "ESPDMX.h"
#include <HardwareSerial.h>



#define dmxMaxChannel  512
#define defaultMax 512

#define DMXSPEED       256000
#define DMXFORMAT      SERIAL_8N2
#define BREAKSPEED     83333
#define BREAKFORMAT    SERIAL_8N1

bool dmxStarted = false;
int sendPin = 4;		//dafault on ESP32
int receivePin = -1;

//DMX value array and size. Entry 0 will hold startbyte
uint8_t dmxData[dmxMaxChannel] = {};
int chanSize;

HardwareSerial DMXSerial(1);

void DMXESPSerial::init() {
  chanSize = defaultMax;

  DMXSerial.begin(DMXSPEED, DMXFORMAT, receivePin, sendPin);
  pinMode(sendPin, OUTPUT);
  dmxStarted = true;
}

// Set up the DMX-Protocol
void DMXESPSerial::init(int chanQuant, int dmxPin) {
  sendPin = dmxPin;

  if (chanQuant > dmxMaxChannel || chanQuant <= 0) {
    chanQuant = defaultMax;
  }

  chanSize = chanQuant;

  DMXSerial.begin(DMXSPEED, DMXFORMAT, receivePin, sendPin);
  pinMode(sendPin, OUTPUT);
  Serial.print("DMX SendPin");
  Serial.println(sendPin);
  
  dmxStarted = true;
}

// Function to read DMX data
uint8_t DMXESPSerial::read(int Channel) {
  if (dmxStarted == false) init();

  if (Channel < 1) Channel = 1;
  if (Channel > dmxMaxChannel) Channel = dmxMaxChannel;
  return(dmxData[Channel]);
}

// Function to send DMX data
void DMXESPSerial::write(int Channel, uint8_t value) {
  if (dmxStarted == false) init();

  if (Channel < 1) Channel = 1;
  if (Channel > chanSize) Channel = chanSize;
  if (value < 0) value = 0;
  if (value > 255) value = 255;

  dmxData[Channel] = value;
}

void DMXESPSerial::end() {
  delete dmxData;
  chanSize = 0;
  DMXSerial.end();
  dmxStarted == false;
}

void DMXESPSerial::update() {
  if (dmxStarted == false) init();

  //Send break
  digitalWrite(sendPin, HIGH);
  DMXSerial.begin(BREAKSPEED, BREAKFORMAT, receivePin, sendPin);
  DMXSerial.write(0);
  DMXSerial.flush();
  delay(1);
  DMXSerial.end();

  //send data
  DMXSerial.begin(DMXSPEED, DMXFORMAT, receivePin, sendPin);
  digitalWrite(sendPin, LOW);
  DMXSerial.write(dmxData, chanSize);
  DMXSerial.flush();
  delay(1);
  DMXSerial.end();
}

void DMXESPSerial::updateEx(){
  //send data
  DMXSerial.begin(DMXSPEED, DMXFORMAT, receivePin, sendPin);
  digitalWrite(sendPin, LOW);
  DMXSerial.write(dmxData, chanSize);
  DMXSerial.flush();
  delay(1);
  DMXSerial.end();	
}
// Function to update the DMX bus

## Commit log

2026-07-04 Add PCB Design section to README
    Added a section for PCB design in the README.
2026-07-04 Update README with PCB design information
    Add details about PCB design and power converter.
2026-07-04 Add image to PCB design section in README
    Added image description for PCB design.
2026-07-04 Update PCB design section in README
2026-07-04 Update PCB design description in README
2026-07-04 Update important note for ESP32 support in README
2026-07-04 Revise IP address discovery instructions in README
    Updated instructions for finding the ESP32 IP address.
